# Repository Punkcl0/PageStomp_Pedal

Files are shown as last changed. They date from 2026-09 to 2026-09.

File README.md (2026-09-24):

# PageStomp Pedal 🎸🦶

**PageStomp Pedal** is a DIY Bluetooth page-turning pedal based on an **ESP32-C3**.

It acts as a **Bluetooth HID keyboard** and can be used with an iPad, tablet or computer to control sheet music applications such as **forScore**, **Newzik** or any software supporting keyboard shortcuts.

The enclosure and pedal parts are designed to be **3D printed**.

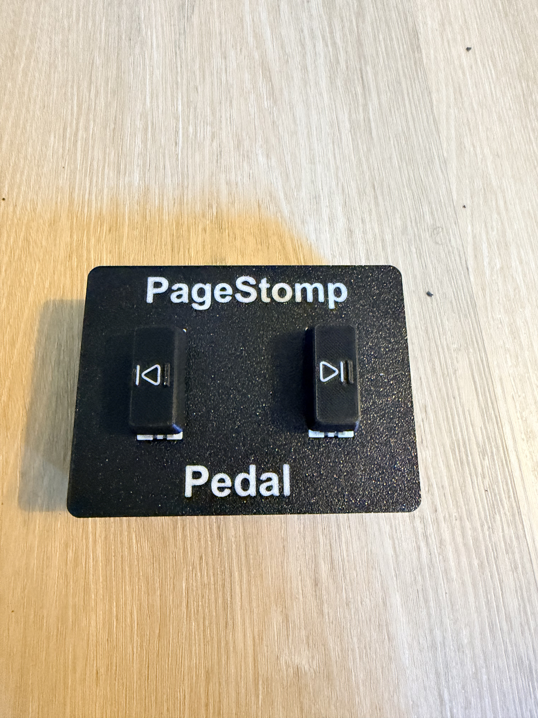
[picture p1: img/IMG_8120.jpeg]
PageStomp Pedal


---

## Features

- ESP32-C3 based
- Bluetooth Low Energy HID keyboard
- Two foot pedals
- Short press support
- Long press support
- Configurable HID keys
- 4 addressable RGB LEDs
- 2 LEDs per pedal
- LED feedback on button press
- Startup LED animation
- Designed for 3D printing
- Powered by a rechargeable 18650 battery
- USB-C battery charging

---

## Default controls

| Pedal | Action | HID key |
|---|---|---|
| Left | Short press | `KEY_LEFT` |
| Left | Long press | `KEY_HOME` |
| Right | Short press | `KEY_RIGHT` |
| Right | Long press | `KEY_END` |

The controls can easily be modified in the firmware:

```cpp
ConfigBouton boutonGauche = {
  KEY_LEFT,
  KEY_HOME
};

ConfigBouton boutonDroit = {
  KEY_RIGHT,
  KEY_END
};
```

---

## LED feedback

The pedal uses **4 WS2812/NeoPixel-compatible LEDs**.

Each pedal is illuminated by two LEDs.

### Startup

At startup, a short purple animation indicates that the controller has powered on.

After startup, the left pedal slowly breathes purple and the right pedal slowly breathes light green, making them easy to identify in dark environments. It's a better way for knowing that the pedal is `ON`.

### LED status summary

| State | Left pedal | Right pedal |
|---|---|---|
| Startup | Purple animation | Purple animation |
| Idle / powered on | Breathing purple | Breathing light green |
| Short press | White flash | White flash |
| Long press | Blue flash | Blue flash |

### Short press

A short button press briefly illuminates the corresponding pedal in white.

### Long press

A long button press briefly illuminates the corresponding pedal in blue.

---

## Hardware

### Main components

- ESP32-C3 Super Mini
- 4 mechanical keyboard switches
- 4 WS2812 / NeoPixel RGB LEDs
- 1 × 18650 Li-ion battery
- USB-C Li-ion charging module
- Power switch
- Wires / connectors
- 3D printed enclosure and pedals
- 4x M3x12 screws

Two mechanical switches are used for each pedal. I used this configurator to generate the 2U keycaps: https://vostoklabs.github.io/SVG-keycap-generator/

The two switches of one pedal are wired in parallel so that pressing either switch activates the corresponding GPIO.

### GPIO assignment

| Function | GPIO |
|---|---:|
| Left pedal | GPIO 5 |
| Right pedal | GPIO 6 |
| NeoPixel data | GPIO 7 |

---

## Wiring

wiring

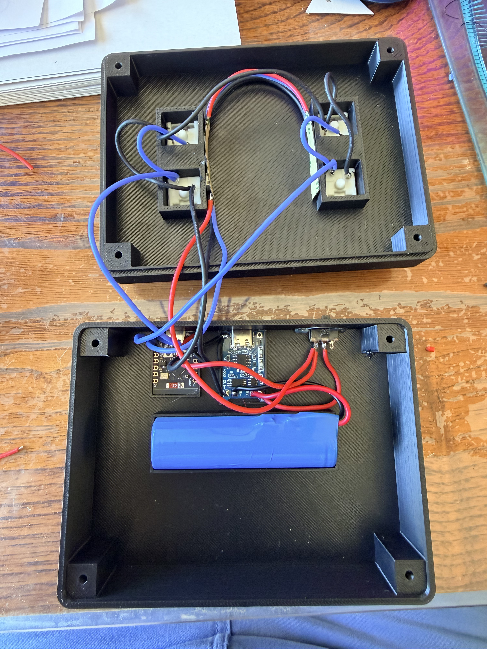
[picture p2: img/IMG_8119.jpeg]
PageStomp wiring


---

## Software

The firmware is written using the Arduino framework.

### Arduino board

Select:

```text
ESP32C3 Dev Module
```

If the serial monitor is used through the ESP32-C3 native USB port, enable:

```text
USB CDC On Boot = Enabled
```

---

## Libraries

The following Arduino libraries are required:

### HijelHID_BLEKeyboard

Used to emulate a Bluetooth HID keyboard.

https://github.com/HijelHub/HijelHID_BLEKeyboard

### Button2

Used for button handling, debouncing, short presses and long presses.

https://github.com/LennartHennigs/Button2

### Adafruit NeoPixel

Used to control the WS2812-compatible RGB LEDs.

https://github.com/adafruit/Adafruit_NeoPixel

---

## Bluetooth

The pedal appears as:

```text
PageStomp Pedal
```

Manufacturer:

```text
Gaston Tech
```

The ESP32 acts as a standard Bluetooth HID keyboard.

This means that no dedicated application or driver is required on the tablet or computer.

Once connected, **PageStomp** simply sends standard keyboard key codes.

---

## Compatible applications

PageStomp should work with any application supporting keyboard shortcuts.

It was designed primarily for sheet music and tablature applications such as:

- forScore
- Newzik
- PDF readers
- Sheet music applications supporting external keyboards

---

## 3D printing

The repository contains the files required to print the pedal enclosure.
I used PETG because it offers better mechanical strength and heat resistance than PLA, which can be useful if the PageStomp Pedal is left inside a car during summer. PLA should nevertheless work fine for normal indoor use.

[MakerWorld link](https://makerworld.com/fr/models/3328558-pagestomp-pedal#profileId-3780158)

---

## Configuration

The default HID actions are grouped in a configuration structure:

```cpp
struct ConfigBouton {
  uint8_t appuiCourt;
  uint8_t appuiLong;
};
```

This makes it easy to change the behavior without modifying the button handling code.

For example:

```cpp
ConfigBouton boutonGauche = {
  KEY_PAGE_UP,
  KEY_HOME
};

ConfigBouton boutonDroit = {
  KEY_PAGE_DOWN,
  KEY_END
};
```

---

## Future ideas

Future improvements:

- [ ] BLE bonding
- [ ] Automatic reconnection to a previously paired device
- [ ] Battery voltage monitoring
- [ ] Battery level indication using the LEDs
- [ ] MAX1704x fuel gauge
- [ ] OLED display
- [ ] Configurable Bluetooth HID actions
- [ ] Non-blocking LED animations
- [ ] Low-power mode

---

## License

### Firmware

The firmware is released under the **MIT License**.

### 3D files

The 3D models are released under the **Creative Commons Attribution-NonCommercial 4.0 International license (CC BY-NC 4.0)**.

You are free to print, modify and share the models for non-commercial purposes, provided appropriate credit is given.

---

## Author

**Gaston Tech**

DIY electronics, automation, 3D printing and unnecessary amounts of RGB lighting. 🎸✨

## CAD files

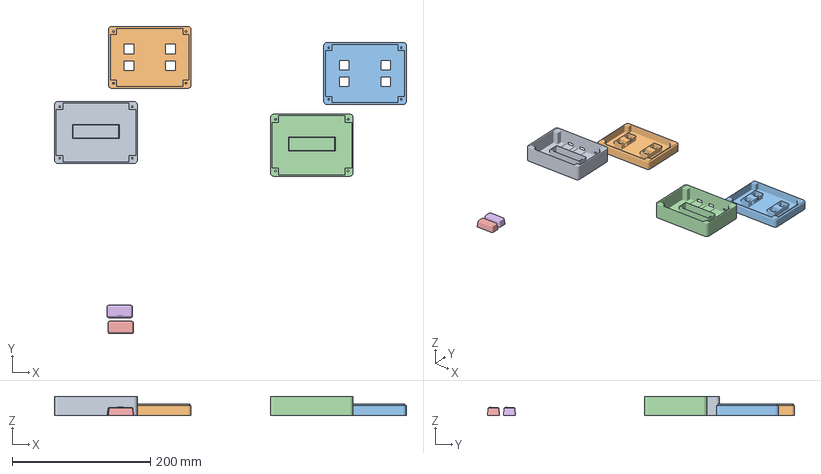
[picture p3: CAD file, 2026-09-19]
3d/3MF/PageStorm.3mf
509.8 x 445.4 x 28.0 mm
Corps1.stl x 2
Corps2.stl x 2
keycap x 2

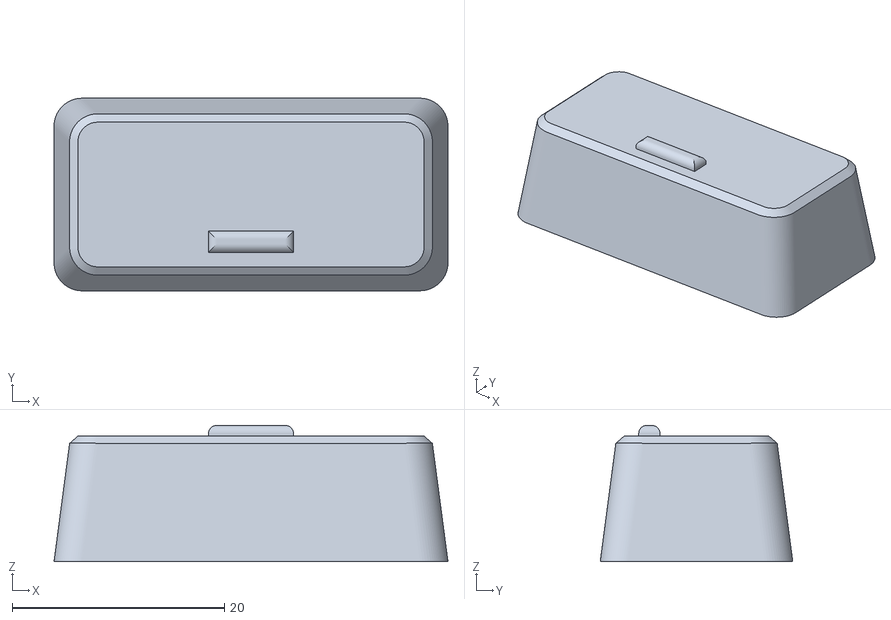
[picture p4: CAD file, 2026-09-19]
3d/STL/keycap.stl
37.1 x 18.1 x 12.8

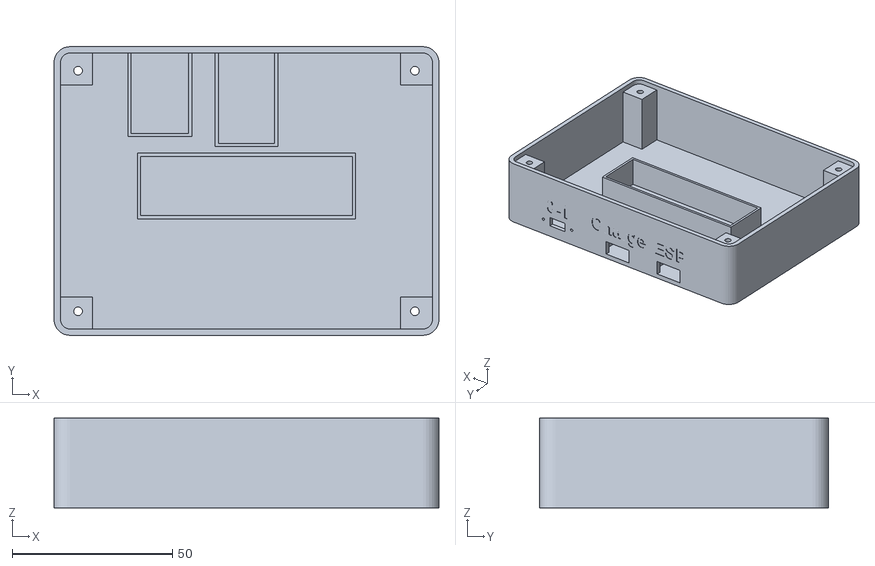
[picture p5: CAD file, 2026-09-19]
3d/STL/Corps1.stl.stl
120.0 x 90.0 x 28.0

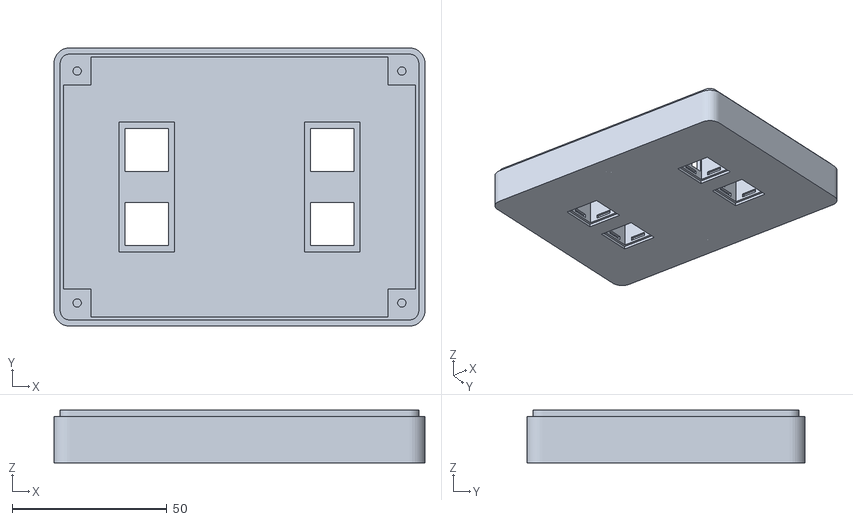
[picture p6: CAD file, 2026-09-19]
3d/STL/Corps2.stl.stl
120.0 x 90.0 x 17.0

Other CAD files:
3d/STL/keycap(1).stl

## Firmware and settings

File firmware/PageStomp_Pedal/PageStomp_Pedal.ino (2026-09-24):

//*************************//
// ESP32-C3
//
// The ESP32 acts as a Bluetooth HID keyboard
// and sends keystrokes to the connected device.
//
// First version:
// - Start BLE
// - Wait for a connection
// - Send data if a button is pressed
//*************************//

#include <HijelHID_BLEKeyboard.h>
#include <Button2.h>
#include <Adafruit_NeoPixel.h>

// Bluetooth
HijelHID_BLEKeyboard keyboard("PageStomp Pedal", "Gaston Tech", 100);

//Leds
constexpr uint8_t PIXEL_PIN = 7;
constexpr uint8_t PIXEL_COUNT = 4;

Adafruit_NeoPixel strip(PIXEL_COUNT, PIXEL_PIN, NEO_GRB + NEO_KHZ800);

//Buttons
constexpr uint8_t LEFT_BUTTON_PIN = 5;
constexpr uint8_t RIGHT_BUTTON_PIN = 6;

Button2 leftBt;    //Left button object
Button2 rightBt;   //Right button object

//Configuration

constexpr unsigned int LONG_CLICK_DELAY = 1500; //Time in ms for detect a long clic from a short clic

struct ConfigBouton {
  uint8_t appuiCourt;
  uint8_t appuiLong;
};

ConfigBouton boutonGauche = {
  KEY_LEFT,
  KEY_HOME
};

ConfigBouton boutonDroit = {
  KEY_RIGHT,
  KEY_END
};

//******************//
// Leds
//******************//

void welcome() {

  for(int a=0; a<4; a++) {  // Repeat 4 times...
    for(int b=0; b<3; b++) { //  'b' counts from 0 to 2...
      strip.clear();         //   Set all pixels in RAM to 0 (off)

      uint32_t color = strip.Color(127, 50, 220);
      // 'c' counts up from 'b' to end of strip in steps of 3...
      for(int c=b; c<strip.numPixels(); c += 3) {
        strip.setPixelColor(c, color); // Set pixel 'c' to value 'color'
      }
      strip.show(); // Update strip with new contents
      delay(100);  // Pause for a moment
      
    }
  }
  strip.clear();
  strip.show();
}

void simplePress(int firstLed, int wait = 500) {
  strip.clear();         //   Set all pixels in RAM to 0 (off)
  for(int i = firstLed; i< firstLed+2; i += 1) {
        uint32_t color = strip.Color(80, 80, 80);
        strip.setPixelColor(i, color); 
      }
  strip.show(); // Update strip with new contents
  delay(wait);  // Pause for a moment
  
  strip.clear();
  strip.show();
}

void longPress(int firstLed, int wait = 500) {
  strip.clear();         //   Set all pixels in RAM to 0 (off)
  for(int i = firstLed; i< firstLed+2; i += 1) {
        uint32_t color = strip.Color(10, 10, 80);
        strip.setPixelColor(i, color); 
      }
  strip.show(); // Update strip with new contents
  delay(wait);  // Pause for a moment

  strip.clear();
  strip.show();
}

void haloDisplay() {

  static uint8_t brightness = 10;
  static int8_t direction = 1;
  static unsigned long lastUpdate = 0;

  if (millis() - lastUpdate < 20) {
    return;
  }

  lastUpdate = millis();

  brightness += direction;

  if (brightness >= 70) {
    brightness = 70;
    direction = -1;
  }

  if (brightness <= 10) {
    brightness = 10;
    direction = 1;
  }

  // Left button - soft purple
  uint32_t leftColor = strip.Color(
    brightness / 2,
    0,
    brightness
  );

  // Right button - pale green
  uint32_t rightColor = strip.Color(
    brightness / 3,
    brightness,
    brightness / 3
  );

  strip.setPixelColor(0, leftColor);
  strip.setPixelColor(1, leftColor);

  strip.setPixelColor(2, rightColor);
  strip.setPixelColor(3, rightColor);

  strip.show();
}


//******************//
// Helpers
//******************//

void leftClick(Button2& btn) {
  if (keyboard.isPaired()) {
    keyboard.tap(boutonGauche.appuiCourt);
    //Serial.println("Left click"); //Uncomment for debug
    simplePress(0,250);
  }
}

void rightClick(Button2& btn) {
  if (keyboard.isPaired()) {
    keyboard.tap(boutonDroit.appuiCourt);
    //Serial.println("Right click"); //Uncomment for debug
    simplePress(2,250);
  }
}
void leftLongClick(Button2& btn) {
  if (keyboard.isPaired()) {
    keyboard.tap(boutonGauche.appuiLong);
    //Serial.println("Left Long click"); //Uncomment for debug
    longPress(0);
  }
}
void rightLongClick(Button2& btn) {
  if (keyboard.isPaired()) {
    keyboard.tap(boutonDroit.appuiLong );
    //Serial.println("Right long click"); ////Uncomment for debug
    longPress(2);
  }
}

//******************//
// Setup
//******************//

void setup() {
  //Serial.begin(115200); //Uncomment for debug

  leftBt.begin(LEFT_BUTTON_PIN );
  rightBt.begin(RIGHT_BUTTON_PIN);

  leftBt.setClickHandler(leftClick);
  rightBt.setClickHandler(rightClick);

  leftBt.setLongClickHandler(leftLongClick);
  rightBt.setLongClickHandler(rightLongClick);

  leftBt.setLongClickTime(LONG_CLICK_DELAY);
  rightBt.setLongClickTime(LONG_CLICK_DELAY);

  //Serial.println("Starting BLE keyboard..."); //Uncomment for debug
  keyboard.begin();

  strip.begin(); // Initialize NeoPixel strip object (REQUIRED)

  welcome();
  delay(10);

  strip.show();  // Initialize all pixels to 'off'
}

//******************//
// Loop
//******************//

void loop() {

  leftBt.loop();
  rightBt.loop();

  haloDisplay(); //Lights on

}
